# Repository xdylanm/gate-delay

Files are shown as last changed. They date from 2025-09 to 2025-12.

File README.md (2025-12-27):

# Gate Delay

A gate delay module in the Eurorack format. The module is implemented with an ATTiny13a microcontroller, with features including

* delays ranging from about 8ms to 2s
* gate pulse length is maintined
* sequences of up to 4 pulses can be delayed

A second, fully analog design is also described. This design is based on a current mirror and integration capacitor, and also maintains the gate pulse length. I have not implemented and tested this one.

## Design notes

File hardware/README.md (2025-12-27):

The 'dual-gate-delay' project contains the hardware design for the v1.0 module. The 'gate-delay' project only contains schematic sketches (for reference related to the analog variant of the design). The 'ic-gate-delay' project is the v2.0 module (single gate delay with expanded IO).

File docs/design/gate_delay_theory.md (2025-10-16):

# Analog Gate Delay Theory

## References

1.  Aaron Lanterman, "ECE4450 L18: Exponential Voltage-to-Current
    Conversion & Tempco Resistors",
    [[youtube](https://www.youtube.com/watch?v=ZWJhApUmfEU)]
2.  Hal Chamberlain, *Musical Applications of Microprocessors*, 2nd Ed.,
    Hayden Books, 1985
3.  Paul Horowitz and Winfield Hill, *The Art of Electronics*, 3rd Ed.,
    Cambridge University Press, 2015
4.  Rene Schmitz, "A tutorial on exponential converters and temperature
    compensation",
    [[schmitzbits.de](https://schmitzbits.de/expo_tutorial/index.html)]
5.  Paul Gray, et al., *Analysis and Design of Analog Integrated
    Circuits*, 4th Ed., Wiley, 2001

# Delay Timing

The delay timing is set the IV relationship for the capacitors:

$$I = C \frac{dV}{dt} \to t_d = \frac{C V_P}{i_p}$$

where $t_d$ is the delay time, $C$ is the capacitance of the timing
capacitors, and $V_P$ is the positive threshold voltage of the Schmitt
trigger inverter.

**Constraints**

-   $V_P = 6V$
-   $C = 100nF$
-   let the current range from 0.5uA to 500uA
-   nominal control voltages range from 0 to 5V

With these assumptions,

$$\begin{aligned}
t_d = \left\{
\begin{array}{ll}
2\mathrm{ms}, & i_p = 300\mu\mathrm{A} \\
1000\mathrm{ms}, & i_p = 0.6\mu\mathrm{A}
\end{array}
\right.
\end{aligned}$$

## Exponential Voltage to Current Conversion

To enable exponential control of the delay time, this design uses a
differential pair to convert a control voltage to a current. Following
the derviation in Lanterman's lecture
([youtube](https://www.youtube.com/watch?v=ZWJhApUmfEU)), the
exponential voltage to current conversion is derived. Note that this
design requires the opposite relationship betwen input control voltage
(CV) and programming current: increasing delay (increasing CV) decreases
the current to timing capacitors.

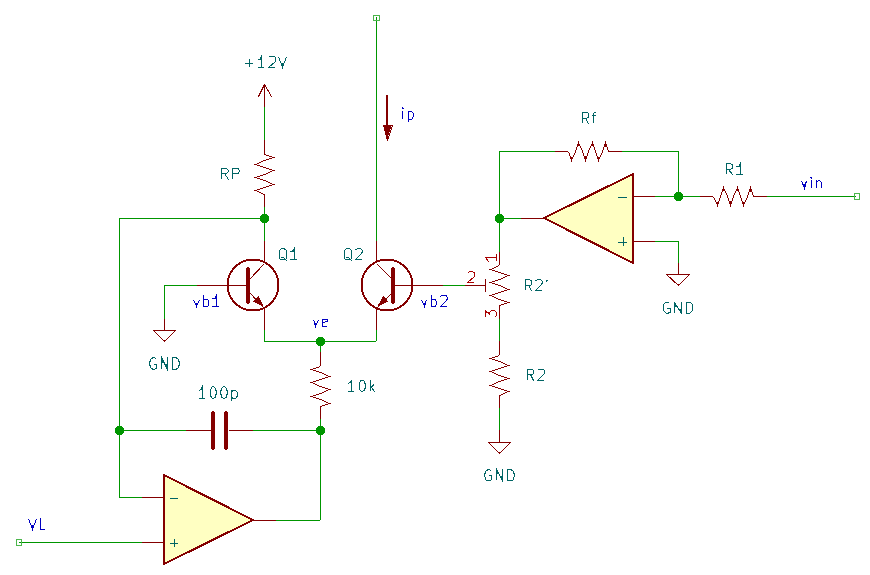
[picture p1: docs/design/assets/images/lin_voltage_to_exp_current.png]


Using the relationship between $v_{be}$ and $i_c$ for a BJT
($i_c = I_S \exp\left(v_{be}/V_T\right)$) and assuming that the
transistors are matched, the collector current in Q2 ($i_{c2}$) is
related to the difference in the voltages at the bases when the emitters
are at the same voltage $v_e$. Grounding the base of *Q1* (not Q2) gives

$$i_{c2} = i_{c1}\exp\left(\frac{v_{b2}}{V_T}\right)$$

The voltage difference across $R_P$ sets the reference current
$I_{ref} = i_{c1}$. The voltage on the high side is set by the supply
and on the low side by the op-amp, which replicates the reference
voltage $V_L$ at the non-inverting input to the collector of Q1.

To establish the desired gain of an input stage, let
$v_{b2} = A v_{in}$. When the input voltage travels over the full range
(0-5V), the programming current should *decrease* by a factor of 1000
(500uA to 0.5uA):

$$\begin{aligned}
i_{p,max} &= I_{ref} \exp \left(\frac{A v_{in}}{V_T}\right) \\
\frac{i_{p,max}}{1000} &= I_{ref} \exp \left(\frac{A (v_{in} +\Delta v_{in})}{V_T}\right) \\
\to 1000 &= \exp \left(\frac{-A \Delta v_{in}}{V_T}\right) \\
\to A &= -\frac{V_T \ln 1000}{5} = -1.3816 V_T
\end{aligned}$$

The value of $I_{ref}$ will be equal to $i_{p,max}$ when $v_{in} = 0$.
This will set the shortest delay time.

Using an op-amp in an inverting gain and a voltage divider to supply
$v_{b2}$

$$\begin{aligned}
A &= -1.3816 V_T = -0.03578 \simeq -\frac{1}{28} = -\frac{R_f}{R_1} \frac{R_2 + \alpha R'_2}{R_2 + R'_2} \\
\to \frac{1}{28} &= \frac{10\mathrm{k}\Omega}{270\mathrm{k}\Omega} \frac{1.93\mathrm{k}\Omega}{2\mathrm{k}\Omega}
\end{aligned}$$

where $R'_2$ is adjusted such that the voltage divider gives a gain of
$\frac{27}{28}$.

## Temperature Compensation

Continuing with Lanterman's derivation, replace $R_f$ with a tempco
resistor, $R_f = R_0[1+\alpha(T-T_0)]$ where $\alpha$ is the thermal
coefficient (note: use $A'$ in place of $\tilde{\mathfrak{s}}$)

$$\begin{aligned}
A = -\frac{R_f}{R_1}A' &= -\frac{R_0[1+\alpha(T-T_0)]}{R_1}A' = -\underbrace{1.3816}_{B} V_T \\
\to \frac{R_0[1+\alpha(T-T_0)]}{R_1}A' &= \frac{kT}{q}B = \frac{k[T_0 + (T-T_0)]}{q}B \\
&= \underbrace{\frac{kT_0}{q}}_{V_{T0}}B + \frac{kT_0}{q}\frac{(T- T_0)}{T_0}B \\
\to \frac{R_0}{R_1}A' + \frac{\alpha R_0 (T-T_0)}{R_1}A' &= \underbrace{V_{T0}B}_{A_0} + \frac{V_{T0}}{T_0}B (T- T_0) \\
\to A_0 &= \frac{R_0}{R_1}A' = V_{T0}B \\
\to \frac{\alpha R_0 (T-T_0)}{R_1}A' &= A_0 \alpha(T-T_0) = V_{T0}B\frac{1}{T_0}B (T- T_0) \\
\to \alpha &= \frac{1}{T_0} = 0.0034
\end{aligned}$$

Note that the temperature coefficient is positive. It\'s hard to find
3300ppm tempco resistors in 2025, so here\'s an alternative derivation
where $R_f = R_{f1}\parallel R_{f2}$ where $R_{f1}$ is a tempco resistor
and $R_{f2}$ is a regular resistor (assumed constant in temperature).

$$\begin{aligned}
R_{f1}\parallel R_{f2} &= \frac{R_{f1}R_{f2}}{R_{f1} + R_{f2}} \\
&= \frac{R_0[1+\alpha(T-T_0)]R_{f2}}{R_0[1+\alpha(T-T_0)] + R_{f2}} \\
&= R_0\frac{1 + \alpha(T-T_0)}{\frac{R_0}{R_{f2}}[1+ \alpha(T-T_0)] + 1} \\
&= R_0\frac{1 + \alpha(T-T_0)}{\left(1 + \frac{R_0}{R_{f2}}\right) + \underbrace{\frac{R_0}{R_{f2}}\alpha}_{\alpha'}(T-T_0)} \\
\end{aligned}$$

Assuming $\alpha'(T-T_0) \ll 1$ (prefer $R_{f2} > R_0$)

$$\frac{1}{p + \alpha(T-T_0)} \approx \frac{1}{p} - \frac{\alpha(T-T_0)}{p^2}$$

such that

$$\begin{aligned}
R_{f1}\parallel R_{f2} &\approx R_0\left[1 + \alpha(T-T_0)\right]\left(\frac{R_{f2}}{R_0 + R_{f2}}\right) \left[ 1 - \frac{R_{f2}\alpha'(T-T_0)}{R_0 + R_{f2}}\right] \\
&= \left(\frac{R_0 R_{f2}}{R_0 + R_{f2}}\right)\left[1 + \alpha(T-T_0)\right] \left[ 1 - \underbrace{\frac{R_0}{R_0 + R_{f2}}}_{\gamma}\alpha(T-T_0)\right] \\
&= \left(\frac{R_0 R_{f2}}{R_0 + R_{f2}}\right)\left[1 + \alpha(T-T_0)\right] \left[ 1 - \gamma\alpha(T-T_0)\right] \\
&= \left(\frac{R_0 R_{f2}}{R_0 + R_{f2}}\right)\left[1 + (1-\gamma)\alpha(T-T_0) - \gamma\alpha^2(T-T_0)^2\right]\\
\end{aligned}$$

Given an available PTC resistor with resistance $R_0$ and temperature
coefficient $\alpha_0 > \alpha = 0.0034$, the parallel resistance
$R_{f2}$ can be found as

$$\begin{aligned}
\alpha &= (1-\gamma)\alpha_0 = \left(1 - \frac{R_0}{R_0 + R_{f2}}\right)\alpha_0 \\
\to \frac{R_0}{R_0 + R_{f2}} &= 1 - \frac{\alpha}{\alpha_0} \\
\to \frac{R_0\alpha_0}{\alpha_0 - \alpha} &= R_0 + R_{f2} \\
\to R_{f2} &= R_0\left(\frac{\alpha_0}{\alpha_0 - \alpha} - 1\right) = R_0\left(\frac{\alpha}{\alpha_0 - \alpha}\right)
\end{aligned}$$

The following table collects a few currently manufactured parts
available on Digikey (as of 2025):

|Mfg. |Part \# |Package |$R_0\ (\mathrm{k}\Omega)$  |$\alpha (\mathrm{ppm/K})$|
|---|---|---|---|---|
|KOA Speer |LT732ATTD202J3900  |0805 |2 |3900|
|KOA Speer |LT732ATTD102J3600  |0805 |1 |3600|
|Vishay Dale |TFPT1206L1002FM |1206 |10 |4110|
|Vishay Dale |TFPTL15L5001FL2B |THT 2.5mm  |5 |4110|
|Texas Instruments  |TMP6131LPGM |TO90-2 |10 |6400|

As an example, the TMP6121LPGM (10k, 6400ppm/C TCR with 1% tolerance) in
parallel with a 12k resistor approximates a 5.45k resistor with a
3400ppm/C temperature with a maximum error of 1.4% over the range from
0-70C.

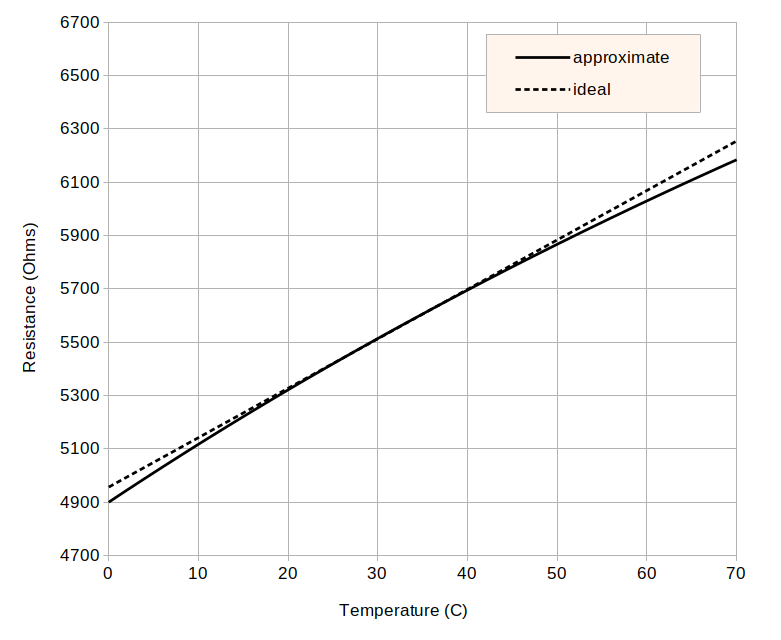
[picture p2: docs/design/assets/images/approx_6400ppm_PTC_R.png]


A second example is the LT732ATTD202J3900 (2k, 3900ppm/C TCR with 10%
tolerance) in parallel with a 12k resistor. This configuration
approximates a 1.714k resistor with a 3400ppm/C TCR to within 0.5% over
the range from 0-70C.

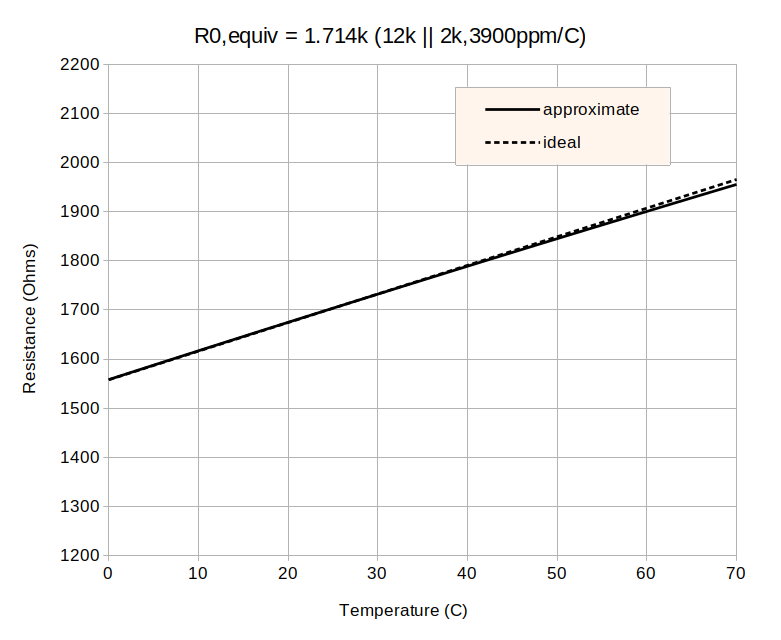
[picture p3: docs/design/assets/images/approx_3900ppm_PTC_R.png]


The updated schematic is shown below.

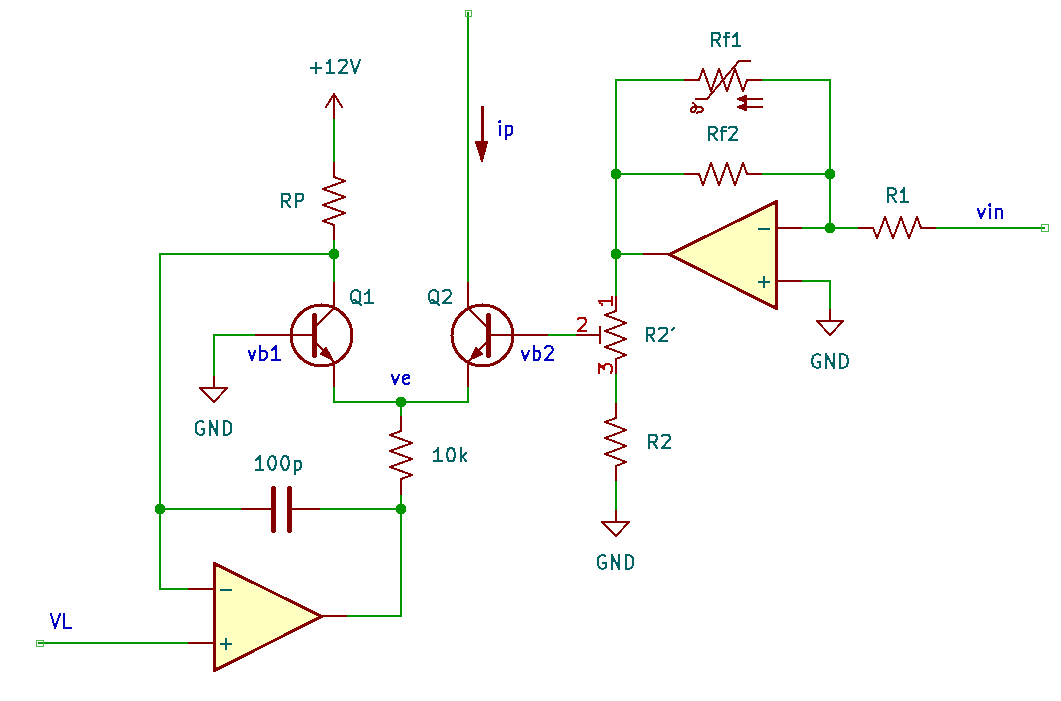
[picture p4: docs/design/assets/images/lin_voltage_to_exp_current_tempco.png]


With $R_{f1}\parallel R_{f2} = 5.454\mathrm{k}\Omega$ (10k PTC
thermistor in parallel with a 12k resistor), $R_1 = 150\mathrm{k}\Omega$
gives an approximate gain in the inverting amplifier of $0.03633$
($1/27.5$) per the design requirement (the remaining fraction can be
tuned in a $100\Omega$ trim pot in series with a $2.2\mathrm{k}\Omega$
resistor in the voltage divider).

## Current Mirror

This derivation follows section A.4.1.1 (appendix 1.1 in chapter 4) of
Gray's book (ref. 5).

The programming current is mirrored to both the capacitors
(corresponding to the leading edge and trailing edge delay timing). The
key design requirement is the match between these two copies of the
current: errors in the ratio of the copy to the programming current are
more tolerable.

The base voltages (relative to ground) of all transistors in the current
mirror are equivalent by construction:

$$\begin{aligned}
v_{b} &= V_{CC} - i_{e}R_E - v_{be} \\
&= V_{CC} - \frac{i_{c}}{\alpha_F} R_E - V_T \ln \frac{i_{c}}{I_S}
\end{aligned}$$

Taking the difference of these equations for Q2 and Q3 (note: in Gray,
there is a beta helper as Q2, so the numbering is different)

$$\frac{i_{c2}}{\alpha_{F2}} R_{E2} - \frac{i_{c3}}{\alpha_{F3}} R_{E3} + V_T \ln \frac{i_{c2}}{I_{S2}} - V_T \ln \frac{i_{c3}}{I_{S3}} = 0$$

Defining *average* and *mismatch* parameters, e.g.
$i_c = 1/2(i_{c2}+i_{c3})$ and $\Delta i_c = i_{c3}-i_{c2}$, and using
assumptions

-   $Delta i_c / 2i_c \ll 1$
-   $\ln (1+x) \simeq x$ if $x \ll 1$

the voltage equation yields the following relationship for the current
error (see Gray Eq. 4.296):

$$\begin{aligned}
\mathrm{let} A &= \frac{g_m R_E}{\alpha_F} \\
\frac{\Delta i_c}{i_c} &= \left(\frac{1}{1 + A} \right)\frac{\Delta I_S}{I_S} + \frac{A}{1+A}\left(-\frac{\Delta R_E}{R_E} + \frac{\Delta \alpha_F}{\alpha_F}\right)
\end{aligned}$$

Recall that $\alpha_F = \frac{\beta_F}{1 + \beta_F} \approx 1$ and
$g_m = i_c/V_T$ such that the term $A$ is the ratio of the (average)
voltage drop across $R_E$ to $V_T$. This leads to the following
conclusions

1.  If $A \gg 1$, the effect of the mismatch between transistors Q2 and
    Q3 is reduced by $\sim 1/A$.
2.  The negative sign in the second term indicates that an intentional
    difference between $R_{E2}$ and $R_{E3}$ can be used to cancel the
    error due to $\alpha_F$.
3.  $R_E$ increases the output impedance of the transistor, reducing the
    current error due to the dependence of $i_c$ on $v_{ce}$ (Early
    effect). This can reduce the error
    $\epsilon \propto \Delta i_c / i_c$ from
    $\epsilon ~ \frac{\Delta v_{ce}}{V_A}$ to
    $\frac{\Delta v_{ce}}{V_A(1+A)}$.

Combined, emitter degeneration with a voltage drop of $>10V_T$ and an
intentional difference can significantly reduce the current mismatch in
the output branches of the current mirror. However, this is limited by
the requirement to maintain the transistors in the forward active
region: $V_{cc} - V_{out,max} = v_{ce,sat.} + i_{e}R_E$. Given

-   $V_{cc} = 11.4$ V
-   $V_{out,max} = 9.1$ V (Zener voltage)
-   $v_{ce,sat.} = 0.3$ V (BC557)
-   $i_{c,max} = 500\mu$ A (design)

then $R_E < 5.2\mathrm{k}\Omega$ (choose $R_E =4.7\mathrm{k}\Omega$).
Note that $V_{RE} ~ 0$ when the current drops below $10\mu\mathrm{A}$,
so this approach has limited effectiveness for low currents (longer
delay times).

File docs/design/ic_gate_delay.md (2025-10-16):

# ATTiny13A Gate Delay Design

## Input

-   Use the edge triggered interrupt on the pin and a state variable to
    read rising & falling edges.
-   Read the ADC and calculate the delay time on the leading edge of the
    gate pulse.

## Delay Timing

Ideally, we'd like to calculate $t_d = T_{d0} \exp( a x )$ where
$T_{d0}$ is the minimum delay time (e.g. 2ms), $x$ is the ADC value
(0-1023) and $a$ is a scaling parameter that sets the maximum delay time
(e.g. 2s). In practice, this is not well suited for the ATTiny, which
doesn't support floating point calculations. Instead, I'll approximate
this function using the upper 3 bits of the ADC value to generate an
exponential, and use the remaining lower bits to linearly interpolate
between.

$$k_d = k_{d0} 2^{b_{9-7}} (1 + b_{6-0} / 2^{7} )$$

With a minium delay of $k_{k0}$ and a maximum of
$k_{d0} 2^8 = 256 k_{d0}$.

Using the upper four bits increases the maximum to $k_{d0} 2^16$, which
is possible if kd0 = 1 (this introduces a large deadband for small k). 

$$k_d = 2^{b_{9-6}} (1 + b_{5-0} / 2^{6} )$$

While correct mathematically, to implement this we need to take care not
to overflow. Expanding

$$\begin{aligned}
k_d &= 2^{b_{hi}} (1 + b_{lo} / 2^{n_\ell} ) \\
    &= 2^{b_{hi}} + b_{lo} * 2^{b_{hi}} / 2^{n_\ell} \\
    &= 2^{b_{hi}} + b_{lo} * 2^{b_{hi} - n_\ell}
\end{aligned}$$

```c++
#define NLOBITS 7       // 10-bit ADC val, 3 upper and 7 lower
#define MINTCKS 36      // lowest number of ticks (*0.213ms)
uint16_t adc_to_delay(uint16_t adc_val) 
{
    uint8_t ubits = (adc_val >> NLOBITS) & 0x07;
    uint8_t lbits = adc_val & 0x007F;

    uint32_t kd = (1 << ubits);
    kd *= MINTCKS;
    kd += (kd * lbits) >> NLOBITS;

    return uint16_t(kd);
}
```

Here, `kd` is the number of timer ticks to count and
`kd0` is the scaling factor that sets the minimum delay.

The gate delay algorithm is implemented in the [Gate Delay Calculation](gate_delay_calc.ipynb) notebook.

## Timers

The internal clock on the ATTiny13A defaults to 9.6MHz. A single
timer/counter (TC) is available with prescalings of 8, 64, 256, or 1024.
With a prescaling of 8, the timer overflow interrupt (TIM0\_OVF\_vect)
will create a clock with a period of 0.213us. This is used to increment
a tick counter, which is the reference clock for the delay.

## Control Flow

Time 0 is indexed to the leading edge of the gate (interrupt). At this
event,

-   the current value of the tick counter is recorded as the start time,
    and
-   the ADC value is read and the delay (in number of ticks) is
    calculated. Add this to the start time to get the start of the
    output pulse (if this results in an overflow, flag it).

On the trailing edge of the gate input (interrupt), compute the gate
pulse length and determine the stop time of the output pulse (flag if
overflow).

On a TC overflow, increment the tick counter. It will overflow
approximately every 14 seconds.

Poll the tick counter value to determine when to start and stop the
output pulse. To avoid missing a tick step, a secondary FIFO is used
which can buffer ticks until they can be consumed in the polling loop.

Multiple pulses can be tracked using a FIFO. The start, stop and state
of each pulse is stored.

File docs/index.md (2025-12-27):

# Gate Delay

A gate delay module in the Eurorack format. 

* Module size: 2HP (10mm)
* Power: 19mA (+12V); 9mA (-12V)

!!! repository "Project Source"

    The project files, including schematic and layout, are available on [github](https://github.com/xdylanm/gate-delay)

## Features

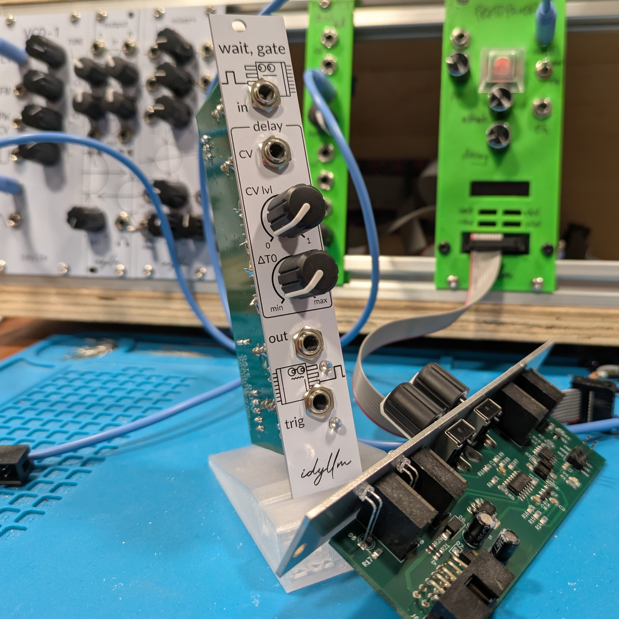
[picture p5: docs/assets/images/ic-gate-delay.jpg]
Gate Delay v2 PCB


The module is implemented with an ATTiny13a microcontroller, with features including

* delays ranging from about 8ms to 2s (CV and offset potentiometer inputs)
* gate pulse length is maintained
* sequences of up to 4 pulses can be delayed
* pulse and 1ms trigger outputs at 5V

A second, fully analog design is also described. This design is based on a current mirror and integration capacitor, and also maintains the gate pulse length. I have not implemented or tested this one.

## Documentation

[Design](theory.md)

[Assembly Guide](assembly.md)

[Schematic](assets/schematic.pdf)

## Changelog

### 2.0.20251111

* Removed the second copy of the delay circuit
* Expanded delay control: 
    * CV with independent attenuation 
    * Separate manual delay offset
* Added a 1ms trigger output

### 1.0.20250917

* Original dual gate delay version (two copies with second gate input normaled to the first)
* CV input normaled with a DC bias to multiplex the attenuation/manual control of the delay
* Output delayed gate pulses with 5V amplitude

## References / Inspiration

1.  [YuSynth Gate Delay](https://yusynth.net/Modular/EN/GATEDELAY/index.html)
2.  [Dopefer A-162 Dual Trigger Delay](https://doepfer.de/a162.htm)
3.  Spend some time reading old modwiggler forum threads\...

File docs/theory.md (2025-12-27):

# Design Overview

## Functional Choices

There are a few behaviours in the gate delay that could be interesting:

* Exponential or linear delay control: the YuSynth design chooses exponential, which makes sense to me.
* CV control over gate delay.
* Maintain the length of the gate pulse: neither the YuSynth nor Dopefer A-162 have this option. The A-162 enables manual control over the ouput pulse length.
* Maintain the amplitude of the gate pulse (assuming it's constant). The YuSynth module includes a slew out.
* Alternate trigger delay mode or "convert to trigger" input: convert an incoming signal to a fixed-duration pulse.

## Design Options

There are a few different approaches that I've considered:

1.  Pure analog delay. This circuit delays the gate pulse in time while
    maintaining its length with exponential CV (and manual offset) for
    the delay time. It might be possible to match the gate amplitude by
    incorporating a S/H circuit, but that seems like it's going too
    far. More details are given in the section [Analog Gate Delay](design/gate_delay_theory.md)
2.  Use a tiny microcontroller. This is the smart way to do it. This is
    elaborated in the section [IC Gate Delay](design/ic_gate_delay.md)
3.  Use a 555. To maintain the pulse duration, two 555's are required,
    and the circuit ends up looking quite similar to the pure analog
    verison.

The pure analog delay is an interesting design exercise. With the IC delay, delayed sequences of pulses are possible. Additionally, by going to a single circuit, it's more straightforward to add improved signal conditioning for the CV input (attenuation and offset) and a trigger output while staying in a 4HP form.

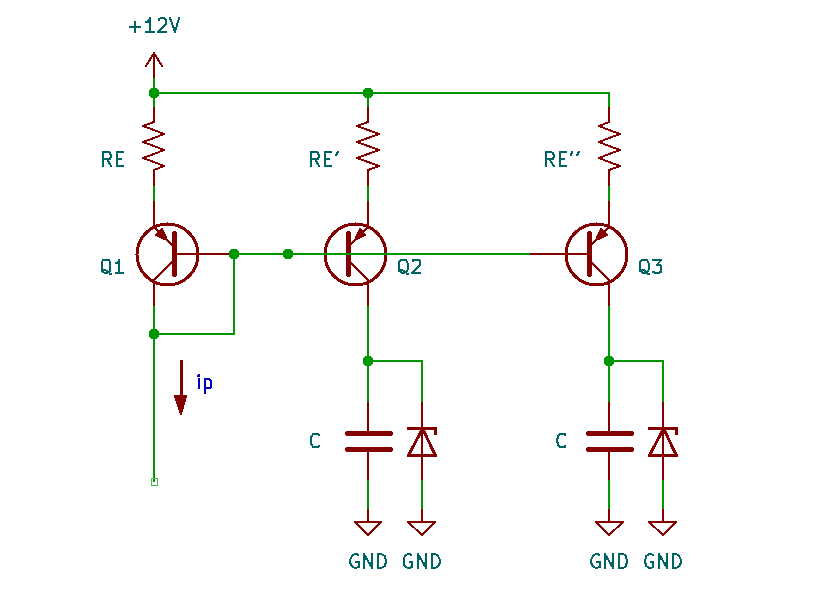
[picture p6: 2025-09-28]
docs/design/assets/images/current_mirror.png

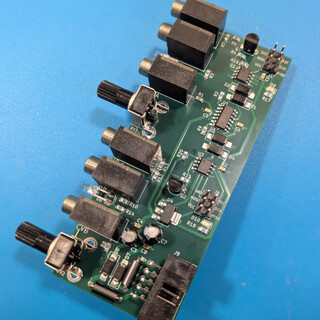
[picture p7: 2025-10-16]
docs/assets/images/gate-delay-1sm.jpg

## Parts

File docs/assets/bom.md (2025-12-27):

| Reference | Qty | Value | Footprint |
| --- | --- | --- | --- |
| C1,C5,C6,C7,C8 | 5 | 100n | 0805 |
| C2 | 1 | 10n | 0805 |
| C3,C4 | 2 | 10u | Radial D5.0mm P2.50mm |
| D1 | 1 | Red LED | 0805 |
| D2,D3,D6,D7 | 4 | B140Q-13-F  | SMA |
| D4,D5 | 2 | Red LED 3mm | LED D3.0mm |
| J1,J2,J3,J4 | 4 | WQP-PJ323M  | WQP-PJ323M |
| J5 | 1 | Pin header  | 02x03 P2.54mm Vertical |
| J6 | 1 | IDC header  | 02x05 P2.54mm Horizontal |
| Q1,Q2,Q3 | 3 | BC847 | SOT-23 |
| R1,R11,R17 | 3 | 4k7 | 0805 |
| R2,R13,R14,R16,R19 | 5 | 10k | 0805 |
| R3,R4,R6,R7,R8,R9,R10 | 7 | 100k | 0805 |
| R5,R12,R18 | 3 | 1k | 0805 |
| R15 | 1 | 150k | 0805 |
| R20,R21 | 2 | 10R | 0805 |
| RV1,RV2 | 2 | B100k | Bourns PTV09A Horizontal |
| U1 | 1 | ATtiny13A-S | SOIC-8 3.9x4.9mm |
| U2 | 1 | TL074 | SOIC-14 3.9x8.7mm |
| U3 | 1 | AMS1117-5.0 | SOT-223-3 |

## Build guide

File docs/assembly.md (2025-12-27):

# Assembly Guide

## Populate Back Side SMT Components

1. Schottky diodes D2, D3, D6, D7
2. Ferrite beads (or 10R): R20, R21
3. BJTs Q1-Q3
4. SMT LED D1
5. ICs U1-U3
6. SMT capacitors C2, C1, C5-C8
7. SMT resistors R1-R19

## Populate Front Side THT Components

1. IDC header J6
2. Electrolytic capacitors C3 & C4
3. Programming header J5
4. Mono jacks J1-J4
5. Potentiometers RV1 & RV2

Populate red 3mm LEDs D4 & D5 with face plate mounted. Leads need to be formed to a 90 degree bend; watch the orientation.

## Programming and Test

Open the firmware project with PlatformIO and connect a USBISP to the programming header on the PCB (check the orientation relative to the ground pin). Flash the firmware.

Test by sending gate pulses to the input. The LEDs will visually indicate the timing of the delayed pulses, or an oscilloscope can be used to check shorter delays.

## BOM

[Download (.csv)](assets/bom.csv)

{%include-markdown "assets/bom.md"%}

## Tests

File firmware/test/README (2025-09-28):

Test Cases

1. test_timer: test overflow and interval behaviour (out of date)
2. test_adc_to_delay: test ADC value conversion to delay in ticks (writes .csv)

To build, run make test. To clean, run make clean.

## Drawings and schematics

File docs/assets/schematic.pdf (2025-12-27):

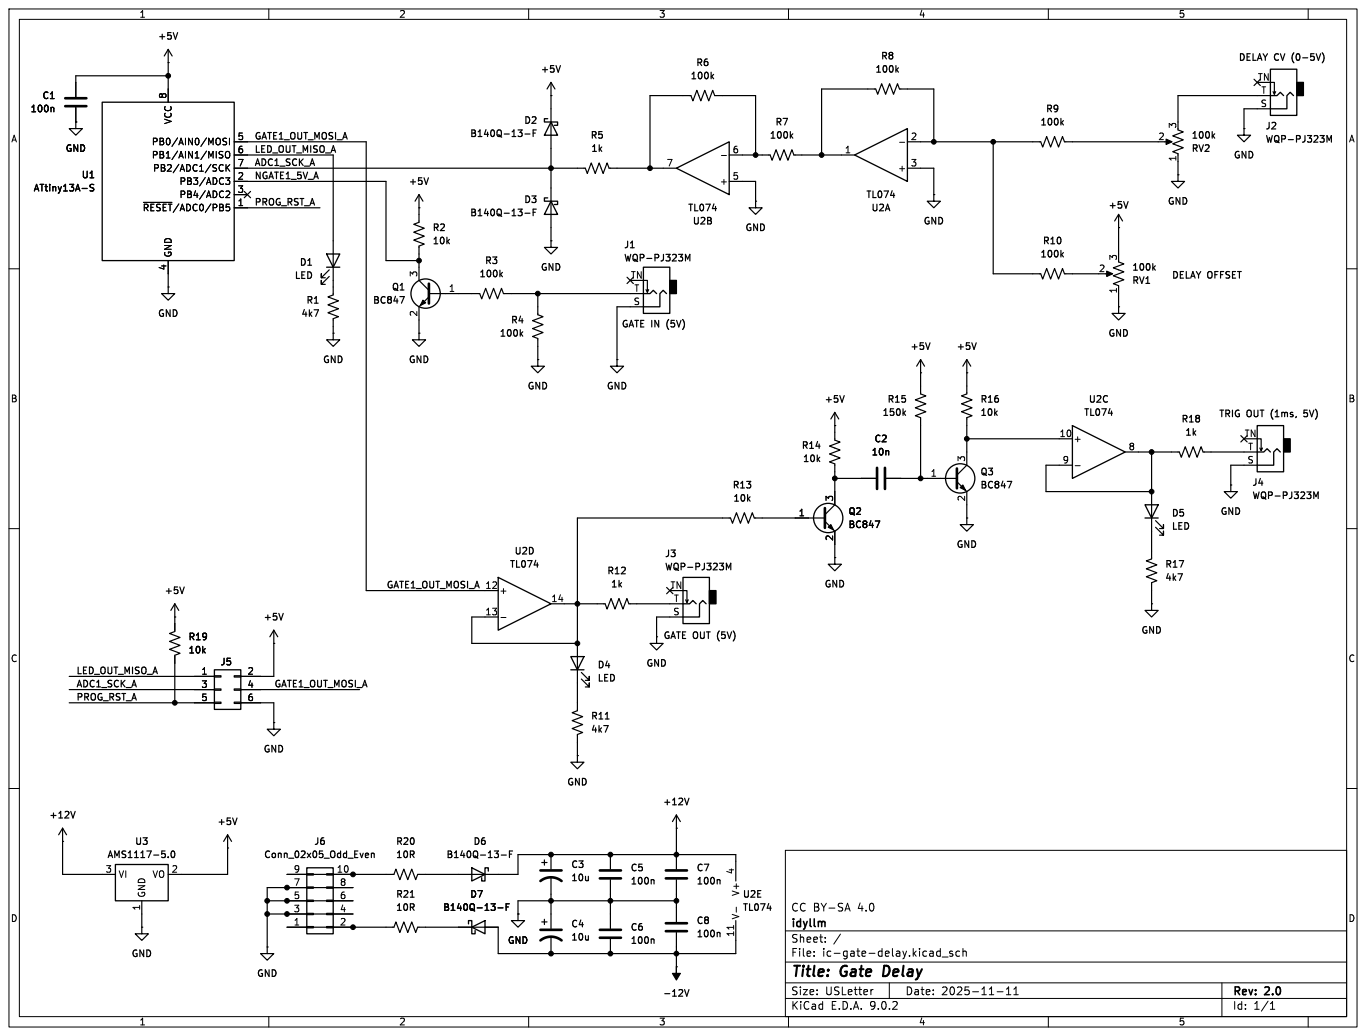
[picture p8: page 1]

4 PB0/AIN0/MOSI 5 PB1/AIN1/MISO 6 PB2/ADC1/SCK 7 PB3/ADC3 2 PB4/ADC2 3 ~{RESET}/ADC0/PB5 1 C1
100k GND

4 PB0/AIN0/MOSI 5 PB1/AIN1/MISO 6 PB2/ADC1/SCK 7 PB3/ADC3 2 PB4/ADC2 3 ~{RESET}/ADC0/PB5 1 U1 ATtiny13A-S GND GND

idyllm
File: ic-gate-delay.kicad_sch Sheet: /
Id: 1/1 Title: Gate Delay

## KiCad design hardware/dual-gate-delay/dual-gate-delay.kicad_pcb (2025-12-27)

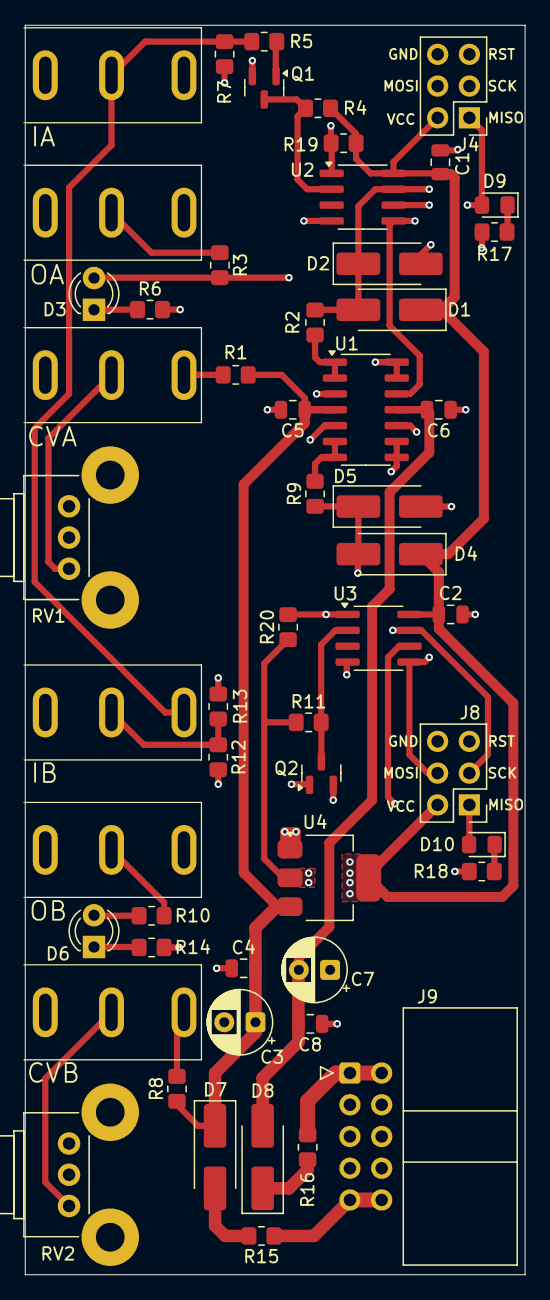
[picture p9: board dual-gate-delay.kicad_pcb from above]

Board: 4 copper layers, 40.0 x 100.0 mm, 55 parts (0 on the bottom side), 38 nets.

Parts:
C1, C2, C4, C5, C6, C8: 100n; C_0805_2012Metric
C3, C7: 10u; CP_Radial_D5.0mm_P2.50mm
D1, D2, D4, D5, D7, D8: B140Q-13-F; D_SMA_Handsoldering
D3, D6: LED; LED_D3.0mm
D9, D10: LED; LED_0805_2012Metric_Pad1.15x1.40mm_HandSolder
J1, J2, J3, J5, J6, J7: MonoJack; Jack_3.5mm_QingPu_WQP-PJ323M_Horizontal
J4, J8: Conn_02x03_Odd_Even; PinHeader_2x03_P2.54mm_Vertical
J9: Conn_02x05_Odd_Even; IDC-Header_2x05_P2.54mm_Horizontal
Q1, Q2: BC847; SOT-23
R1, R8: 120k; R_0805_2012Metric_Pad1.20x1.40mm_HandSolder
R2, R3, R9, R10: 1k; R_0805_2012Metric_Pad1.20x1.40mm_HandSolder
R4, R6, R11, R14, R17, R18: 4k7; R_0805_2012Metric_Pad1.20x1.40mm_HandSolder
R5, R7, R12, R13: 100k; R_0805_2012Metric_Pad1.20x1.40mm_HandSolder
R15, R16: 10R; R_0805_2012Metric_Pad1.20x1.40mm_HandSolder
R19, R20: 10k; R_0805_2012Metric_Pad1.20x1.40mm_HandSolder
RV1, RV2: 100k; Potentiometer_Bourns_PTV09A-2_Single_Horizontal
U1: TL074; SOIC-14_3.9x8.7mm_P1.27mm
U2, U3: ATtiny13A-S; SOIC-8_3.9x4.9mm_P1.27mm
U4: AMS1117-5.0; SOT-223-3_TabPin2

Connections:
+5V: C1.1, C2.1, D1.1 (K), D4.1 (K), J4.2, J8.2, R4.1, R11.1, R19.1, R20.1, U2.8 (VCC), U3.8 (VCC), U4.2 (VO)
+12V: C3.1, C4.1, C5.1, D7.1 (K), R1.1, R8.1, U1.4 (V+), U4.3 (VI)
-12V: C6.2, C7.2, C8.2, D8.2 (A), U1.11 (V-)
/ADC1_SCK_A: D1.2 (A), D2.1 (K), J4.3, R2.1, U2.7 (PB2/ADC1/SCK)
/ADC1_SCK_B: D4.2 (A), D5.1 (K), J8.3, R9.1, U3.7 (PB2/ADC1/SCK)
/GATE1_OUT_MOSI_A: J4.4, U1.12 (+), U2.5 (PB0/AIN0/MOSI)
/GATE1_OUT_MOSI_B: J8.4, U1.10 (+), U3.5 (PB0/AIN0/MOSI)
/LED_OUT_MISO_A: D9.2 (A), J4.1, U2.6 (PB1/AIN1/MISO)
/LED_OUT_MISO_B: D10.2 (A), J8.1, U3.6 (PB1/AIN1/MISO)
/NGATE1_5V_A: Q1.3 (C), R4.2, U2.2 (PB3/ADC3)
/NGATE1_5V_B: Q2.3 (C), R11.2, U3.2 (PB3/ADC3)
/PROG_RST_A: J4.5, R19.2, U2.1 (~RESET/ADC0/PB5)
/PROG_RST_B: J8.5, R20.2, U3.1 (~RESET/ADC0/PB5)
GND: C1.2, C2.2, C3.2, C4.2, C5.2, C6.1, C7.1, C8.1, D2.2 (A), D5.2 (A), J1.S, J2.S, J3.S, J4.6, J5.S, J6.S, J7.S, J8.6, J9.3, J9.4, J9.5, J9.6, J9.7, J9.8, Q1.2 (E), Q2.2 (E), R6.2, R7.2, R13.2, R14.2, R17.2, R18.2, RV1.1, RV2.1, U2.4 (GND), U3.4 (GND), U4.1 (GND)
unnamed: D3.2 (A), R3.2, U1.13 (-), U1.14
unnamed: D3.1 (K), R6.1
unnamed: D6.2 (A), R10.2, U1.8, U1.9 (-)
unnamed: D6.1 (K), R14.1
unnamed: D7.2 (A), R15.2
unnamed: D8.1 (K), R16.2
unnamed: D9.1 (K), R17.1
unnamed: D10.1 (K), R18.1
unnamed: J1.T, RV1.3
unnamed: J1.TN, R1.2
unnamed: J2.T, R3.1
unnamed: J3.T, J7.TN, R5.1, R7.1
unnamed: J5.T, RV2.3
unnamed: J5.TN, R8.2
unnamed: J6.T, R10.1
unnamed: J7.T, R12.1, R13.1
unnamed: J9.1, J9.2, R16.1
unnamed: J9.9, J9.10, R15.1
unnamed: Q1.1 (B), R5.2
unnamed: Q2.1 (B), R12.2
unnamed: RV1.2, U1.3 (+)
unnamed: R2.2, U1.1, U1.2 (-)
unnamed: RV2.2, U1.5 (+)
unnamed: R9.2, U1.6 (-), U1.7

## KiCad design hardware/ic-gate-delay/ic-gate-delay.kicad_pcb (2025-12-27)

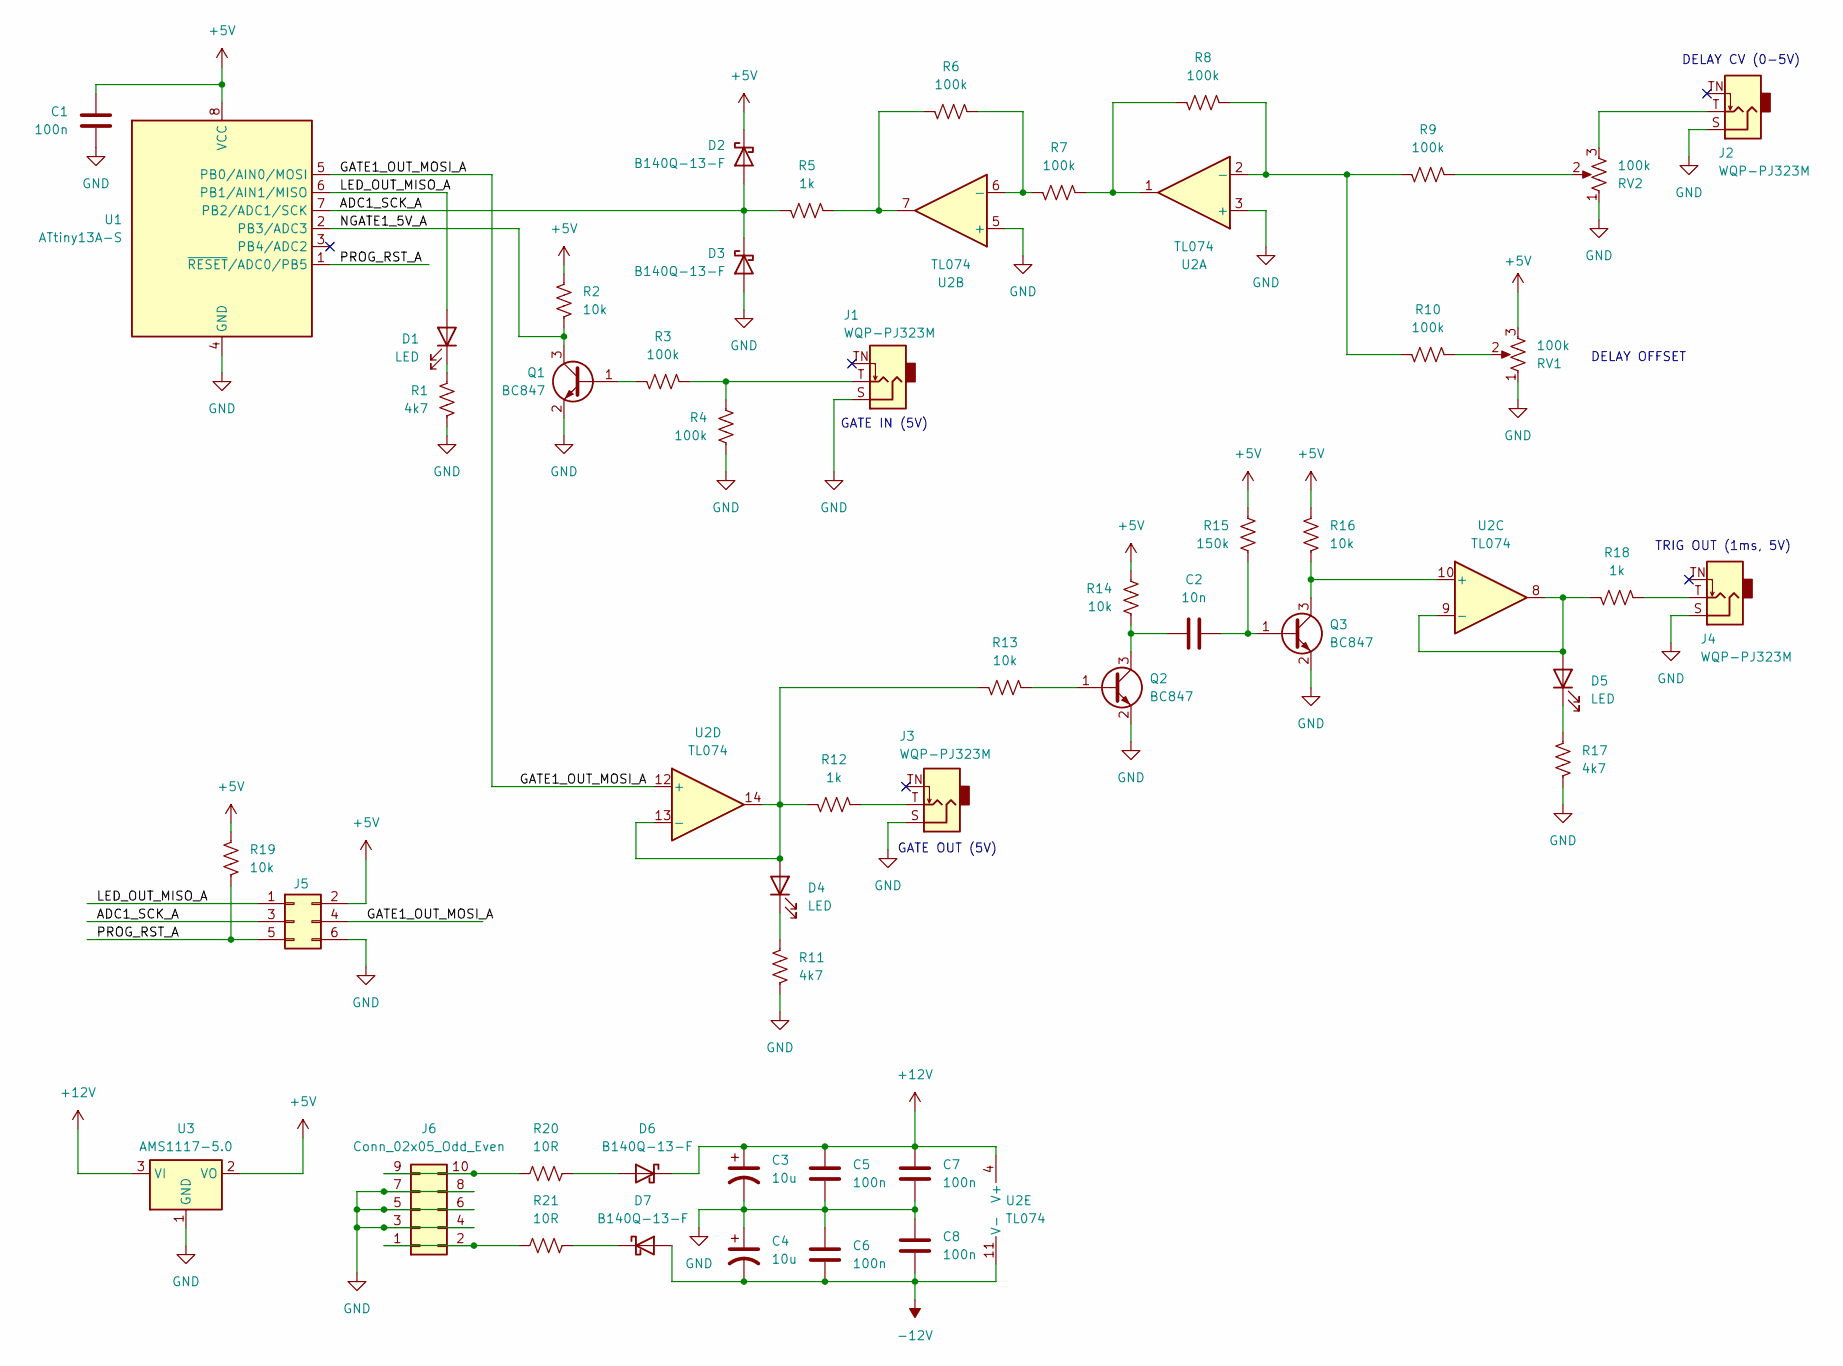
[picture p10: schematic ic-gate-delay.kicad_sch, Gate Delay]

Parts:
C1, C5, C6, C7, C8: 100n; C_0805_2012Metric
C2: 10n; C_0805_2012Metric
C3, C4: 10u; CP_Radial_D5.0mm_P2.50mm
D1: LED; LED_0805_2012Metric_Pad1.15x1.40mm_HandSolder
D2, D3, D6, D7: B140Q-13-F; D_SMA_Handsoldering
D4, D5: LED; LED_D3.0mm
J1, J2, J3, J4: WQP-PJ323M; Jack_3.5mm_QingPu_WQP-PJ323M_Horizontal
J5: Conn_02x03_Odd_Even; PinHeader_2x03_P2.54mm_Vertical
J6: Conn_02x05_Odd_Even; IDC-Header_2x05_P2.54mm_Horizontal
Q1, Q2, Q3: BC847; SOT-23
R1, R11, R17: 4k7; R_0805_2012Metric_Pad1.20x1.40mm_HandSolder
R2, R13, R14, R16, R19: 10k; R_0805_2012Metric_Pad1.20x1.40mm_HandSolder
R3, R4, R6, R7, R8, R9, R10: 100k; R_0805_2012Metric_Pad1.20x1.40mm_HandSolder
R5, R12, R18: 1k; R_0805_2012Metric_Pad1.20x1.40mm_HandSolder
R15: 150k; R_0805_2012Metric_Pad1.20x1.40mm_HandSolder
R20, R21: 10R; R_0805_2012Metric_Pad1.20x1.40mm_HandSolder
RV1, RV2: 100k; Potentiometer_Bourns_PTV09A-2_Single_Horizontal
U1: ATtiny13A-S; SOIC-8_3.9x4.9mm_P1.27mm
U2: TL074; SOIC-14_3.9x8.7mm_P1.27mm
U3: AMS1117-5.0; SOT-223-3_TabPin2

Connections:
+5V: C1.1, D2.1 (K), J5.2, R2.1, R14.1, R15.1, R16.1, R19.1, RV1.3, U1.8 (VCC), U3.2 (VO)
+12V: C3.1, C5.1, C7.1, D6.1 (K), U2.4 (V+), U3.3 (VI)
-12V: C4.2, C6.2, C8.2, D7.2 (A), U2.11 (V-)
/ADC1_SCK_A: D2.2 (A), D3.1 (K), J5.3, R5.1, U1.7 (PB2/ADC1/SCK)
/GATE1_OUT_MOSI_A: J5.4, U1.5 (PB0/AIN0/MOSI), U2.12 (+)
/LED_OUT_MISO_A: D1.2 (A), J5.1, U1.6 (PB1/AIN1/MISO)
/NGATE1_5V_A: Q1.3 (C), R2.2, U1.2 (PB3/ADC3)
/PROG_RST_A: J5.5, R19.2, U1.1 (~RESET/ADC0/PB5)
GND: C1.2, C3.2, C4.1, C5.2, C6.1, C7.2, C8.1, D3.2 (A), J1.S, J2.S, J3.S, J4.S, J5.6, J6.3, J6.4, J6.5, J6.6, J6.7, J6.8, Q1.2 (E), Q2.2 (E), Q3.2 (E), R1.2, R4.2, R11.2, R17.2, RV1.1, RV2.1, U1.4 (GND), U2.3 (+), U2.5 (+), U3.1 (GND)
unnamed: D1.1 (K), R1.1
unnamed: D4.2 (A), R12.2, R13.2, U2.13 (-), U2.14
unnamed: D4.1 (K), R11.1
unnamed: D5.2 (A), R18.2, U2.8, U2.9 (-)
unnamed: D5.1 (K), R17.1
unnamed: D6.2 (A), R20.2
unnamed: D7.1 (K), R21.2
unnamed: J1.T, R3.1, R4.1
unnamed: J2.T, RV2.3
unnamed: J3.T, R12.1
unnamed: J4.T, R18.1
unnamed: J6.1, J6.2, R21.1
unnamed: J6.9, J6.10, R20.1
unnamed: Q1.1 (B), R3.2
unnamed: Q2.1 (B), R13.1
unnamed: C2.1, Q2.3 (C), R14.2
unnamed: C2.2, Q3.1 (B), R15.2
unnamed: Q3.3 (C), R16.2, U2.10 (+)
unnamed: R5.2, R6.1, U2.7
unnamed: R7.2, R8.1, U2.1
unnamed: R9.2, RV2.2
unnamed: R10.2, RV1.2
unnamed: R8.2, R9.1, R10.1, U2.2 (-)
unnamed: R6.2, R7.1, U2.6 (-)

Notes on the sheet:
DELAY OFFSET
GATE IN (5V)
TRIG OUT (1ms, 5V)
GATE OUT (5V)
DELAY CV (0-5V)

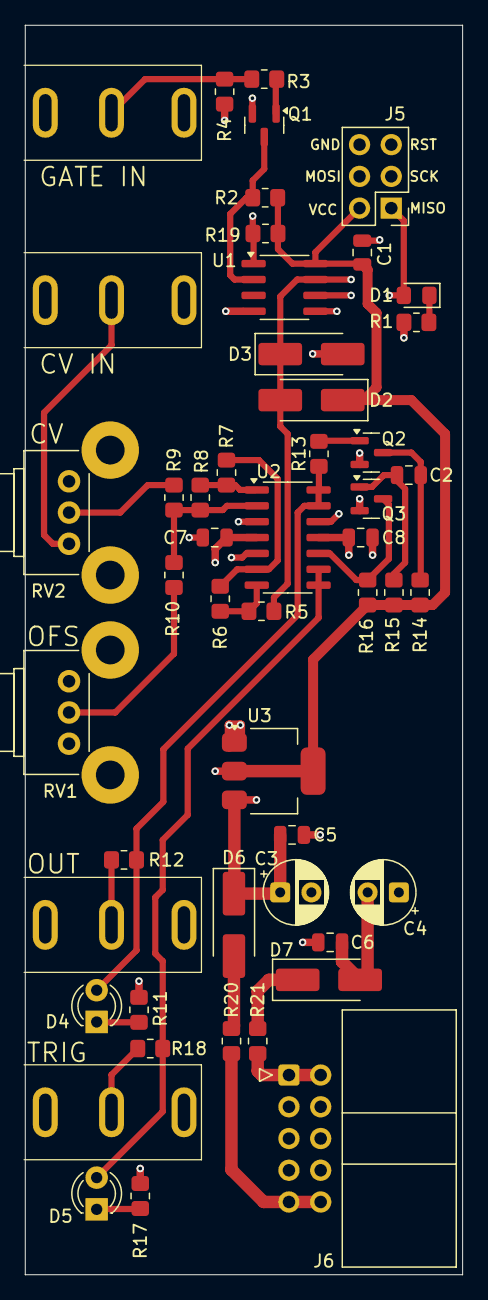
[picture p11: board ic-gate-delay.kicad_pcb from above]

Board: 4 copper layers, 35.0 x 100.0 mm, 50 parts (0 on the bottom side), 33 nets.

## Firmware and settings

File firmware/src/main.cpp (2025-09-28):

// ATTiny13a Pulse Delay Firmware
// Implements: Falling edge detect on PB3, analog delay via ADC1, output pulse on PB0

#include <avr/io.h>
#include <avr/interrupt.h>

#include "adc_to_delay.h"

// Pin definitions
#define INPUT_PIN   PB3
#define OUTPUT_PIN  PB0
#define ANALOG_CH   1 // ADC1

// Timing variables, related to current pin state
volatile uint16_t input_pulse_start = 0;
volatile uint16_t pulse_width = 0;
// 0=wait leading edge, 1=received leading edge, 2=wait trailing edge, 3=processing delayed pulse
volatile uint8_t delay_in_state = 0; 
volatile uint8_t last_pin_state;

// Time tracking (ticks)
volatile uint16_t tick_counter;
volatile uint8_t ticks_pending;
uint16_t tick_current;

// Delayed pulse output
#define PULSE_FIFO_DEPTH 4
#define ACTIVE_PULSE 0x01
#define READY_LEADING_EDGE 0x02
#define READY_TRAILING_EDGE 0x04

struct Pulse 
{
    uint16_t start;
    uint16_t stop;
    uint8_t state;
};
Pulse pulse_fifo[PULSE_FIFO_DEPTH];
uint8_t pulse_head;
uint8_t pulse_tail;

#ifdef EN_DEBUG_PIN
#define DBG_LED_PIN PB1
inline void delay_x10ms(uint8_t const x) 
{
    for (uint8_t n = 0; n < x; ++n) {
        _delay_loop_2(24000); 
    }
}

void debug_blink(uint8_t const nblink, bool const forever=true) 
{
    cli();  // disable global interrupts

    do {
        for (uint8_t i = 0; i < nblink; ++i) {
            PORTB |= (1 << DBG_LED_PIN);    // on
            delay_x10ms(25);
            PORTB &= ~(1 << DBG_LED_PIN);   // off
            delay_x10ms(25);
        }
        delay_x10ms(100);
    } while (forever);

    sei();
}
#endif

uint16_t read_adc(uint8_t const ch) 
{
    ADMUX = (ADMUX & 0xF0) | ch;
    ADCSRA |= (1 << ADSC);
    while (ADCSRA & (1 << ADSC));
    return ADC;
}

void setup() 
{
    // set the main clock to 9.6MHz (no prescale)
    CLKPR = (1 << CLKPCE);  // pre scale change enable
    CLKPR = 0;              // within 4 clocks, 0 = no prescale

    // Set OUTPUT_PIN as output, INPUT_PIN as input
    DDRB |= (1 << OUTPUT_PIN);
    DDRB &= ~(1 << INPUT_PIN);
    PORTB |= (1 << INPUT_PIN); // Pull-up default enabled (MCUCR.PUD=0)
    
    // Set up ADC: Vcc ref, select ADC1, left adjust, prescaler 64
    ADMUX = (1 << MUX0); // ADC1
    ADCSRA = (1 << ADEN) | (1 << ADPS2) | (1 << ADPS1) | (1 << ADPS0) ; // Enable, prescaler 128

    // trigger a conversion to initialize the ADC once
    read_adc(ANALOG_CH);

    // Set up Pin Change Interrupt on PB3
    GIMSK |= (1 << PCIE);
    PCMSK |= (1 << INPUT_PIN);

    delay_in_state = 0;
    last_pin_state = 1;     // active low

    pulse_head = 0;
    pulse_tail = 0;
    for (int8_t i = 0; i < PULSE_FIFO_DEPTH; ++i) {
        pulse_fifo[i].state = 0;
    }

#ifdef EN_DEBUG_PIN
    // Set DBG_LED_PIN as output
    DDRB |= (1 << DBG_LED_PIN);
    debug_blink(3,false);
#endif

    // Set up Timer0: normal mode, prescaler 8
    TCCR0B = (1 << CS01);   // 0b010 clk/8, start
    TCNT0 = 0;              // reset
    TIMSK0 |= (1 << TOIE0); // Enable overflow interrupt

    // set this just before entering the main loop to manage clock jitter with the stack
    tick_counter = 0;
    tick_current = 0;   // tick_counter
    ticks_pending = 0;  // tick_counter - tick_current
        
    sei(); // Enable global interrupts

}

// Pin change interrupt for gate trigger
ISR(PCINT0_vect) 
{
    uint8_t const cur_pin_state = (PINB & (1 << INPUT_PIN)) ? 1 : 0;
    bool const leading_edge = last_pin_state == 1 && cur_pin_state == 0;
    bool const trailing_edge = last_pin_state == 0 && cur_pin_state == 1;

    if (leading_edge && delay_in_state == 0) {
        input_pulse_start = tick_counter;
        delay_in_state = 1;
    } else if (trailing_edge && delay_in_state == 2) {
        uint16_t const input_pulse_end = tick_counter;
        if (input_pulse_end >= input_pulse_start) {
            pulse_width = input_pulse_end - input_pulse_start;
        } else {
            pulse_width = (UINT16_MAX - input_pulse_end) + input_pulse_start + 1;
        }
        delay_in_state = 3;
    }
    last_pin_state = cur_pin_state;
}

// Overflow for TCNT0: T_tick = Prescaler * 256 / F_CPU 
// * prescaler = 1, T_tick = 26us, overflow = 1.7s
// * prescaler = 8, T_tick = 213us, overflow = 14s
ISR(TIM0_OVF_vect) 
{
    tick_counter += 1;   
    ticks_pending +=1 ;
}

void loop() 
{
#ifdef EN_DEBUG_PIN
    if (ticks_pending > 8) {
        debug_blink(2);
    }
#endif

    Pulse* head = &(pulse_fifo[pulse_head]);
    if (delay_in_state == 1) {
    
        // Read analog voltage - expected less than 2 ticks of TCNT0
        uint16_t const adc_val = read_adc(ANALOG_CH);
        uint16_t const delay_ticks = adc_to_delay(adc_val);

        // uint16_t const delay_ticks = read_adc(ANALOG_CH) << 3; 

        // uint16_t const delay_ticks = 4695; // 14085; 
        
        if (head->state == 0) {
            // Important: this copy has to be atomic. On an 8-bit processor, it can get interrupted
            // halfway, resulting in a corrupted copy (e.g. [0000][1111] --> [0001][1111])
            cli();
            head->start = input_pulse_start;
            sei();
            head->start += delay_ticks;
            head->state = (READY_LEADING_EDGE | ACTIVE_PULSE);
    
            delay_in_state = 2; // advance to "wait for trailing edge" state 
        } else {
            delay_in_state = 0; // discard this pulse and wait again
        }
    } else if (delay_in_state == 3) {   // got the trailing edge
        cli();
        head->stop = pulse_width;
        sei();
        head->stop += head->start;
        head->state |= READY_TRAILING_EDGE;

        pulse_head = (pulse_head + 1) % PULSE_FIFO_DEPTH;
        delay_in_state = 0; // advance to "wait for leading edge" state
    } 
    
    Pulse* tail = &(pulse_fifo[pulse_tail]);
    if ((tail->state & READY_LEADING_EDGE) && (tick_current == tail->start)) {
        PORTB |= (1 << OUTPUT_PIN);
        tail->state &= ~(READY_LEADING_EDGE);
    } 
    
    if ((tail->state & READY_TRAILING_EDGE) && (tick_current == tail->stop)) {
        PORTB &= ~(1 << OUTPUT_PIN);
        tail->state = 0;    // remove active & ready trailing
        pulse_tail = (pulse_tail + 1) % PULSE_FIFO_DEPTH;   // consumed
    }

    // checked for edges, pop the tick stack
    if (ticks_pending > 0) {
        tick_current++;
        ticks_pending--;
    }
}

int main(void) 
{
    setup();

    while (1) {
        loop();
    }
    return 0;
}

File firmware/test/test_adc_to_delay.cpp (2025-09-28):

#include "adc_to_delay.h"

#include <fstream>
#include <iostream>

/*
    \brief Run the conversion from ADC value to delay in ticks, write to CSV for comparison
*/
int main() {

    std::ofstream csv_file("adc_to_delay_results.csv");
    csv_file << "adc_val,delay\n";
    for (uint16_t adc_val = 0; adc_val <= 1023; ++adc_val) {
        uint32_t delay = adc_to_delay(adc_val);
        csv_file << adc_val << "," << delay << "\n";
    }
    csv_file.close();
    std::cout << "Results written to adc_to_delay_results.csv\n";


    return 0;
}

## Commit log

2025-09-28 Initial commit to separate repository for this module (previously contained in the ADSR-EG module). Updated docs to build.
    [555-delay.kicad_sch, dual-gate-delay.kicad_pcb, dual-gate-delay.kicad_sch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]
2025-10-16 Migrated to mkdocs/material & some documentation clean up. Added schematic and BOM
2025-11-05 Initial project for dual gate delay faceplate, small PBC revisions (SMT BJTs, moved LED)
    [dual-gate-delay-faceplate.kicad_pcb, dual-gate-delay-faceplate.kicad_sch, dual-gate-delay.kicad_pcb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]
2025-11-11 v2 PCB and faceplate with single gate delay circuit
    [ic-gate-delay-faceplate.kicad_pcb, ic-gate-delay-faceplate.kicad_sch, ic-gate-delay.kicad_pcb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]
2025-12-27 Updates with build from IC gate delay
    [bom.csv]

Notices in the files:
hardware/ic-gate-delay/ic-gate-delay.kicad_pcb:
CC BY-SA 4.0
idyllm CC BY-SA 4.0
